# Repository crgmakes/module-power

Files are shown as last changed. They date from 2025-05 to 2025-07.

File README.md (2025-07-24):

# Simple Power Module

All the source files for the simple power module hardware. This module converts 120VAC or 240VAC to 5VDC @ 2A and also provides 3.3V @ 3A.

# Software 

You will need [KiCad](https://kicad.org) to view and edit this design. Click [here](https://www.kicad.org/download/) to download.

# Automation

When the PCB file is checked in, git will automatically build the output gerber files. When a release is made, git will also automatically build both a single PCB production files as well as the panel for production.

---

THE DESIGN IS PROVIDED "AS IS" AND THE AUTHOR DISCLAIMS ALL WARRANTIES WITH REGARD TO THIS DESIGN INCLUDING ALL IMPLIED WARRANTIES OF MERCHANTABILITY AND FITNESS. IN NO EVENT SHALL THE AUTHOR BE LIABLE FOR ANY SPECIAL, DIRECT, INDIRECT, OR CONSEQUENTIAL DAMAGES OR ANY DAMAGES WHATSOEVER RESULTING FROM LOSS OF USE, DATA OR PROFITS, WHETHER IN AN ACTION OF CONTRACT, NEGLIGENCE OR OTHER TORTIOUS ACTION, ARISING OUT OF OR IN CONNECTION WITH THE USE OR PERFORMANCE OF THIS DESIGN.

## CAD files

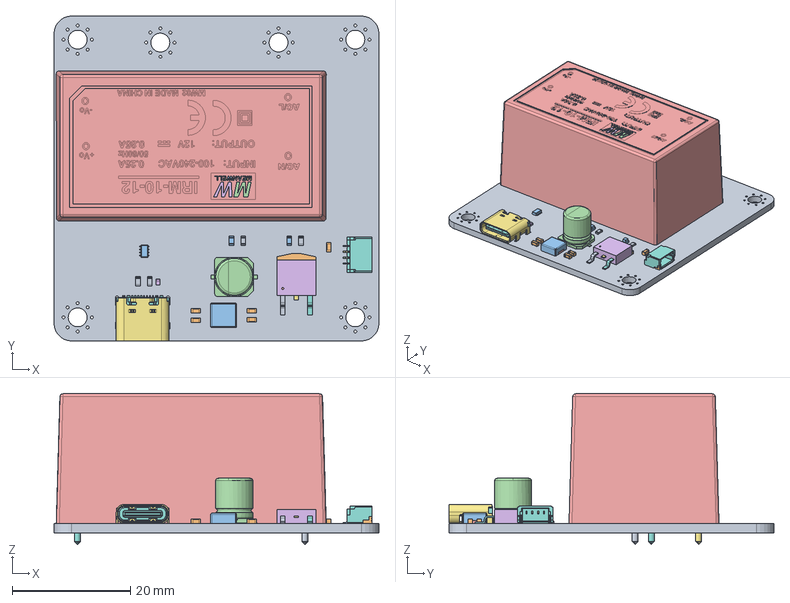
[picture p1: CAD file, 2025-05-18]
cad/power-module.FCStd
55.0 x 55.0 x 25.6 mm
Pcb_a909
SM04B-SRSS-TB v2
SM04B-SRSS-TB v003
SM04B-SRSS-TB v004
SM04B-SRSS-TB v005
SM04B-SRSS-TB v006
SM04B-SRSS-TB v007
SM04B-SRSS-TB v008
R3_R_0603_1608Metric_863d8a166362 x 4
C5_C_0603_1608Metric_8aa0772852b9 x 5
D3_LED_0603_1608Metric_7f0152b93437 x 2
IRM-10-5 v2
IRM-10-5 v003
IRM-10-5 v004
IRM-10-5 v005
IRM-10-5 v006
IRM-10-5 v007
IRM-10-5 v008
IRM-10-5 v009
IRM-10-5 v010
IRM-10-5 v011
IRM-10-5 v012
IRM-10-5 v013
IRM-10-5 v014
IRM-10-5 v015
IRM-10-5 v016
BODY-SOT
C7_CP_Elec_63x77_39e4231ef861
a6dc4f76-8551-11ed-a139-00155d22e2d7_part
a6dc503e-8551-11ed-a139-00155d22e2d7_part
a6dc503e-8551-11ed-a139-00155d22e2d7_part001
D1_D_SOD-882_cb0a772a3ea7
USB4105-GF-A-060_PART2
USB4105-GF-A-060_PART1

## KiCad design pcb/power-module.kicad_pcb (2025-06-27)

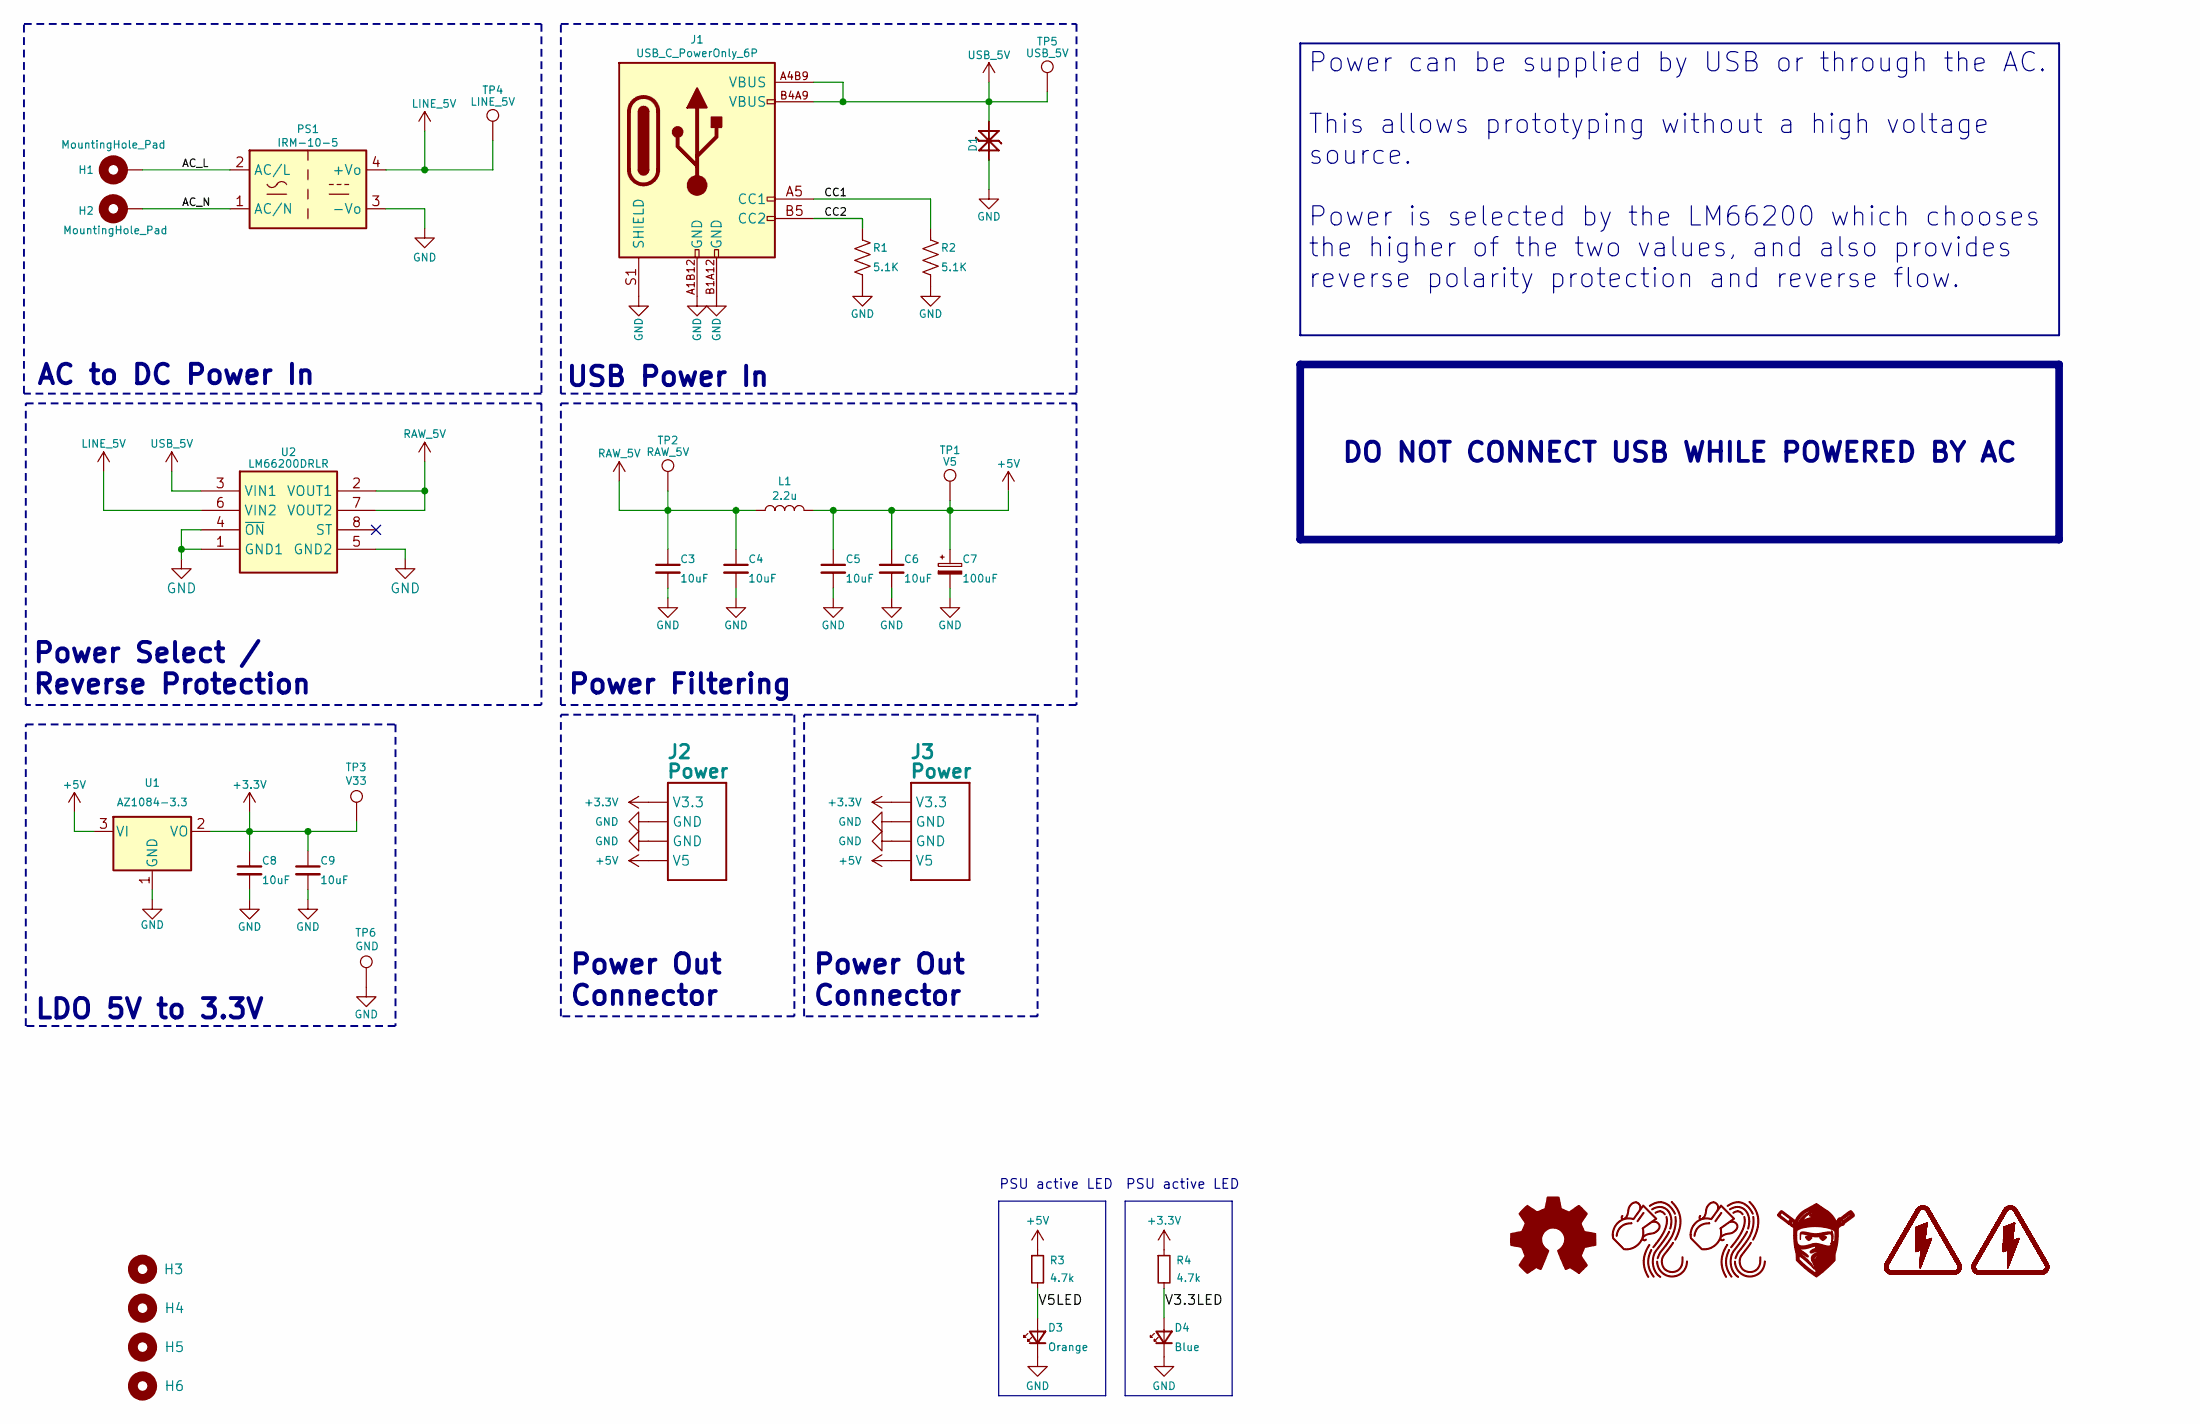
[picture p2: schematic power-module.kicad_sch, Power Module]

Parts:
C3, C4, C5, C6, C8, C9: 10uF; C_0603_1608Metric; MPN CL10A106MO8NQNC; Mouser 187-CL10A106MO8NQNC
C7: 100uF; CP_Elec_6.3x7.7; MPN RVT1V101M0607; Mouser 647-UWT1V101MCL1S
D1: PESD5V5C1BL; DFN1006-2; MPN PESD5V5C1BLYL; Mouser 771-PESD5V5C1BLYL
D3: Orange; LED_0603_1608Metric; MPN XL-1608UOC-06; Mouser 859-LTST-C190KFKT
D4: Blue; LED_0603_1608Metric; MPN XL-1608UBC-04; Mouser 710-150060BS75020
H1, H2: MountingHole_Pad; MountingHole_3.2mm_M3_Pad_Via
H3, H4, H5, H6: MountingHole; MountingHole_3.2mm_M3_Pad_Via
J1: USB_C_PowerOnly_6P; GCT_USB4105-GF-A; MPN USB4105-GF-A-060; Digikey 2073-USB4105-GF-A-060TR-ND
J2, J3: Power; JST_SH_SM04B-SRSS-TB_1x04-1MP_P1.00mm_Horizontal; MPN SM04B-SRSS-TBT(LF)(SN); Mouser 306-SM04BSRSSTBTLFSN
L1: 2.2u; L_Sunlord_MWSA0402S; MPN CMLO0420H2R2MTT; Mouser 673-PA4332222NLT
LOGO1: FNWW Face 10mm
LOGO2: Logo_Open_Hardware_Small; OSHW-Logo_5.7x6mm_SilkScreen
LOGO3: Aquarius Logo 10mm
LOGO4: Aquarius Logo 5mm
PS1: IRM-10-5; Converter_ACDC_MeanWell_IRM-10-xx_THT; MPN IRM-10-5; Mouser 709-IRM10-5
R1, R2: 5.1K; R_0603_1608Metric; MPN FRC0603J512 TS; Mouser 71-CRCW0603J-5.1K-E3
R3, R4: 4.7k; R_0603_1608Metric; MPN FRC0603J472 TS; Mouser 71-CRCW06034K70JNEAC
S1, S2: HIGH-VOLTAGE-5MM
TP1: V5; TestPoint_Pad_D1.0mm
TP2: RAW_5V; TestPoint_Pad_D1.0mm
TP3: V33; TestPoint_Pad_D1.0mm
TP4: LINE_5V; TestPoint_Pad_D1.0mm
TP5: USB_5V; TestPoint_Pad_D1.0mm
TP6: GND; TestPoint_Pad_D1.0mm
U1: AZ1084-3.3; TO-252-2; MPN AZ1084CD-3.3TRG1; Mouser 621-AZ1084CD-3.3TRG1
U2: LM66200DRLR; SOTFL50P160X60-8N; MPN LM66200DRLR; Mouser 595-LM66200DRLR

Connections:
+3.3V: C8.1, C9.1, J2.4 (V3.3), J3.4 (V3.3), R4.1, TP3.1, U1.2 (VO)
+5V: C5.1, C6.1, C7.1, J2.1 (V5), J3.1 (V5), L1.2, R3.1, TP1.1, U1.3 (VI)
/Power Module/AC_L: H1.1, PS1.2 (AC/L)
/Power Module/AC_N: H2.1, PS1.1 (AC/N)
/Power Module/CC1: J1.A5 (CC1), R2.1
/Power Module/CC2: J1.B5 (CC2), R1.1
/Power Module/V3.3LED: D4.2 (A), R4.2
/Power Module/V5LED: D3.2 (A), R3.2
GND: C3.2, C4.2, C5.2, C6.2, C7.2, C8.2, C9.2, D1.1 (K1), D3.1 (K), D4.1 (K), J1.A1B12 (GND), J1.B1A12 (GND), J1.S1 (SHIELD), J2.2 (GND), J2.3 (GND), J3.2 (GND), J3.3 (GND), PS1.3 (-Vo), R1.2, R2.2, TP6.1, U1.1 (GND), U2.1 (GND1), U2.4 (~ON), U2.5 (GND2)
LINE_5V: PS1.4 (+Vo), TP4.1, U2.6 (VIN2)
RAW_5V: C3.1, C4.1, L1.1, TP2.1, U2.2 (VOUT1), U2.7 (VOUT2)
USB_5V: D1.2 (K2), J1.A4B9 (VBUS), J1.B4A9 (VBUS), TP5.1, U2.3 (VIN1)

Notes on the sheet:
AC to DC Power In
Power Out Connector
Power Filtering
USB Power In
PSU active LED
LDO 5V to 3.3V
Power Select / Reverse Protection
DO NOT CONNECT USB WHILE POWERED BY AC
Power can be supplied by USB or through the AC. This allows prototyping without a high voltage source. Power is selected by the LM66200 which chooses the higher of the two values, and also provides reverse polarity protection and reverse flow.

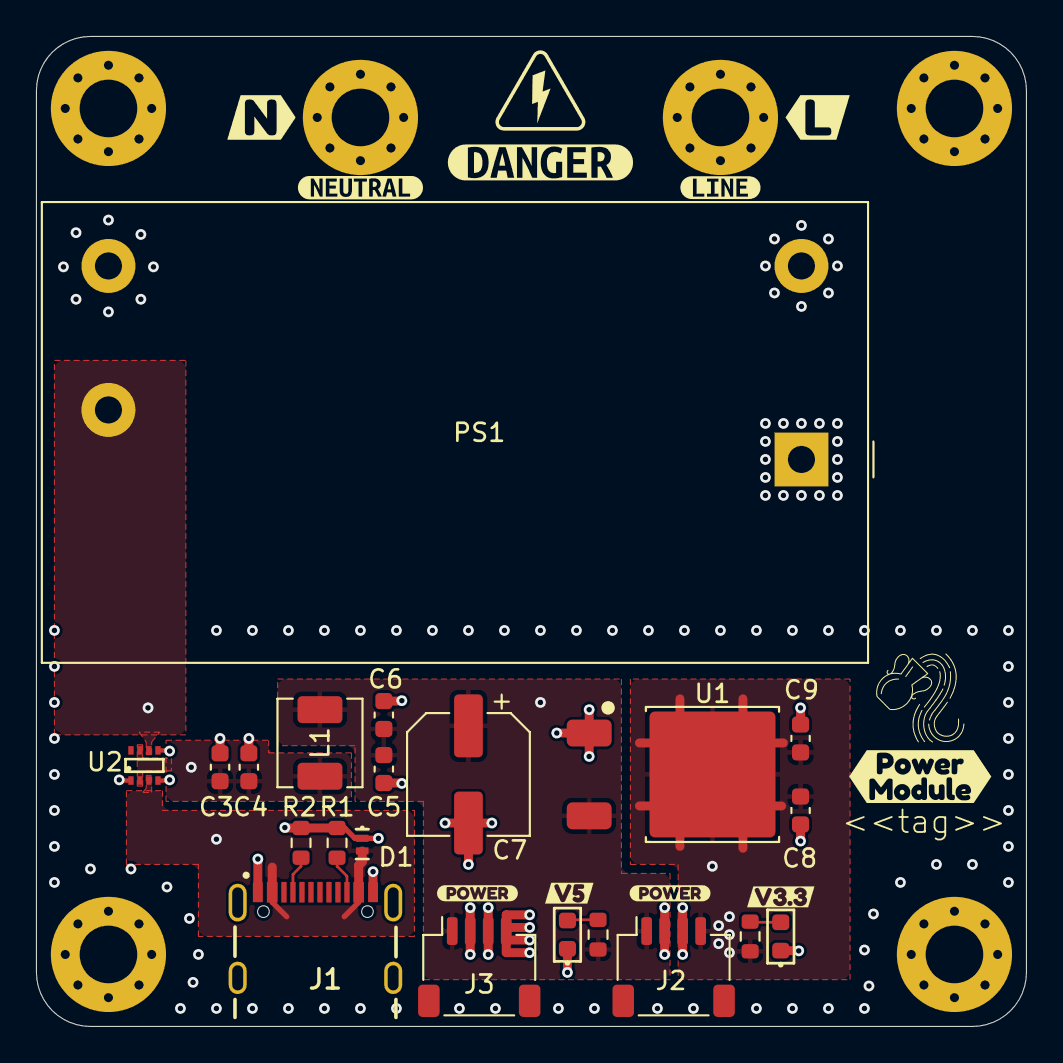
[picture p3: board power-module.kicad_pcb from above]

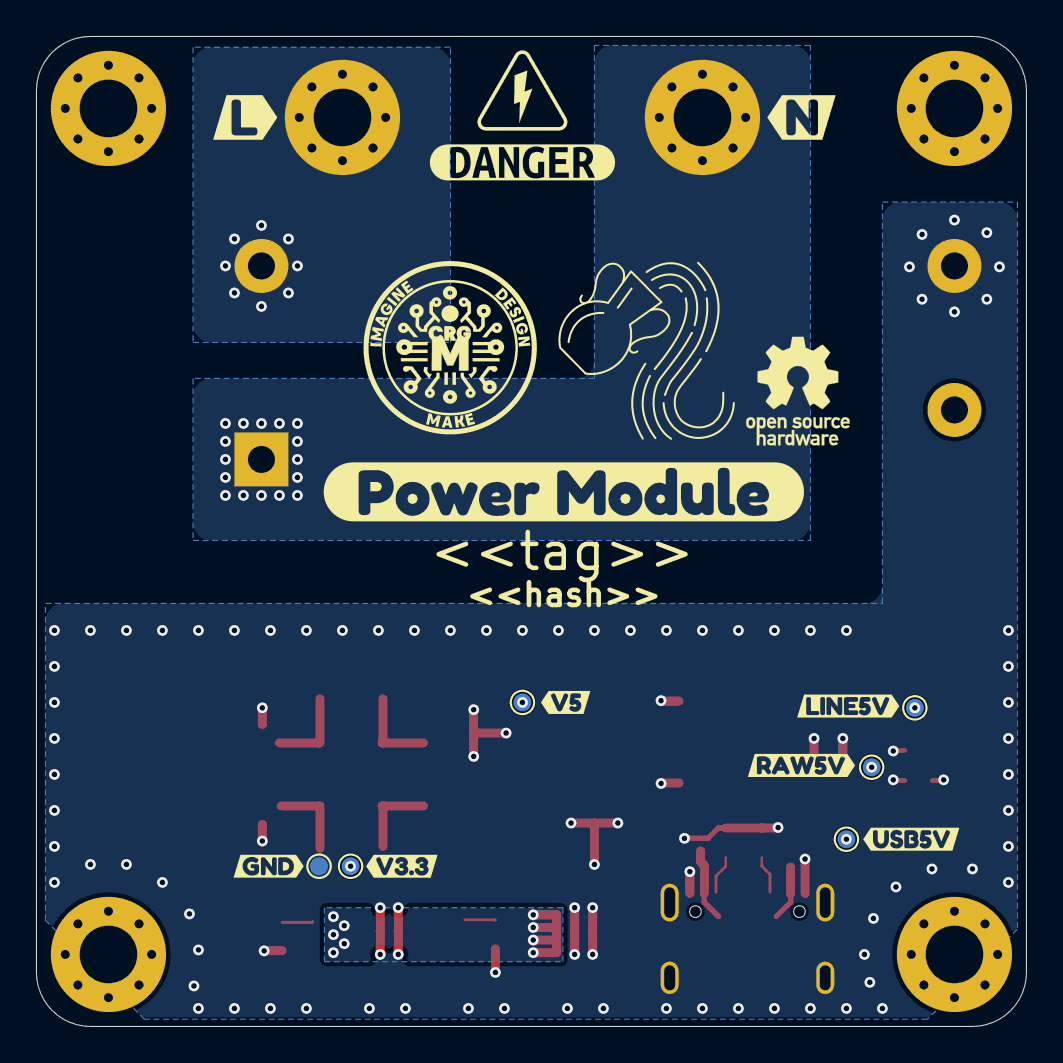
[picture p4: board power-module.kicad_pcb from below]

Board: 4 copper layers, 55.0 x 55.0 mm, 59 parts (20 on the bottom side), 12 nets.

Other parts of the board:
kibuzzard-67E1D06C, kibuzzard-67E1D06C#2: G***; kibuzzard-67E1D06C
kibuzzard-67F465A8: G***; kibuzzard-67F465A8
kibuzzard-67F873C9: G***; kibuzzard-67F873C9
kibuzzard-681CF78D: G***; kibuzzard-681CF78D
kibuzzard-6823F461: G***; kibuzzard-6823F461
kibuzzard-6823F476: G***; kibuzzard-6823F476
kibuzzard-685744FC: G***; kibuzzard-685744FC
kibuzzard-685745D7: G***; kibuzzard-685745D7
kibuzzard-685745EF: G***; kibuzzard-685745EF
kibuzzard-6857402F: G***; kibuzzard-6857402F
kibuzzard-6857403E: G***; kibuzzard-6857403E
kibuzzard-6857452D: G***; kibuzzard-6857452D
kibuzzard-6857464E: G***; kibuzzard-6857464E
kibuzzard-6857482E: G***; kibuzzard-6857482E
kibuzzard-68084394: G***; kibuzzard-68084394
kibuzzard-68574501: G***; kibuzzard-68574501
kibuzzard-68574508: G***; kibuzzard-68574508
kibuzzard-68574514: G***; kibuzzard-68574514
kibuzzard-68574631: G***; kibuzzard-68574631

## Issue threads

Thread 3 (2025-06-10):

LED too bright

cyberreefguru, 2025-06-10:
Increase resistance to lower brightness.
Current value is 1K - consider 4.7K to reduce total part count, even if that's too high.

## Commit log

2025-04-09 Initial checkin
    [power-module-simple.kicad_pcb, power-module-simple.kicad_sch]
2025-04-10 Attribute updates; generated production files
    [bom.csv, designators.csv, positions.csv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]
2025-04-11 Updated silkscreen and LED size
    [power-module-simple.kicad_pcb, power-module-simple.kicad_sch]
2025-04-29 Changed switching mechanism; updated power delivery for v3.3
    [power-module-simple.kicad_pcb, power-module-simple.kicad_sch]
2025-05-08 Fixed AZ1084 footprint
    Fixed USB-C Connector / symbol mismatch
    Moved parts around
    Moved USB-C connector from overhanging.
    Generated ibom.
    [bom.csv, designators.csv, positions.csv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]
2025-05-08 Renamed to power-module; updated silkscreen and some symbols
    [power-module-simple.kicad_pcb, power-module-simple.kicad_sch, power-module.kicad_pcb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]
2025-05-10 generated fabrication files
    [bom.csv, designators.csv, positions.csv]
2025-05-14 Changed LED colors; regenerated panels
    [power-module.kicad_pcb, power-module.kicad_sch]
2025-05-15 Changed to vscore instead of mouse bites
    re-panelized.
    [bom.csv, designators.csv, positions.csv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]
2025-05-16 Updated connector symbol and back annotation
    [power-module.kicad_pcb, power-module.kicad_sch]
2025-05-16 revamped using different examples
    [power-module.kicad_pcb, power-module.kicad_sch]
2025-05-16 getting tired doing it this way....
2025-05-16 optimized script; still fighting some errors
    [power-module.kicad_pcb]
2025-05-17 Updated parameters on some parts
    [power-module.kicad_pcb, power-module.kicad_sch]
2025-05-17 Added extras and crgm lib.
    [power-module.kicad_pcb]
2025-05-17 continue to resolve library issues (pcbdraw)
2025-05-17 fixed syntax error with pcbdraw lib
2025-05-18 Updated models and alignment
    [power-module.FCStd, power-module.kicad_pcb]
2025-05-18 fixed model expansion of usb connector; changed script to use sed
    [power-module.kicad_pcb]
2025-05-24 Added panelization; cleaned up
    [bom.csv, designators.csv, positions.csv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]
2025-05-24 switched to zip action
2025-05-24 switched to fab kit to capture rotations
2025-05-25 moved ibom to directory; zipped gerbers
2025-05-25 fixed back option for zip of gerbers
2025-05-25 adjusted gerber directories
2025-05-25 switched to fabkit for single pcb
2025-05-25 only copy pcb and sch to pcb directory
2025-05-26 fixed model locations in pcb; reworking to use import
    [power-module.kicad_pcb]
2025-05-26 fixed model name and locations
    [power-module.kicad_pcb]
2025-05-26 Fixed soldermask on USB connector; cleaned up scripts
    [power-module.kicad_pcb]
2025-05-26 Fixed USB model path and position, and TO-252 position
    [power-module.kicad_pcb]
2025-05-27 alternate inductor - primary is out of stock
    [power-module.kicad_pcb, power-module.kicad_sch]
2025-05-28 Part swap; moved from 2x2 panel to 1x2 panel
    [power-module.kicad_pcb, power-module.kicad_sch]
2025-05-29 Added tag to pcb to capture version on release; updated check in script to fill in tag
    [power-module.kicad_pcb]
2025-05-31 Separated 22uF into two 10uF; rerouted everything for better layout
    [power-module.kicad_pcb, power-module.kicad_sch]
2025-05-31 Fixed file name in script; fixed H3 name missing in schematic
    [power-module.kicad_pcb, power-module.kicad_sch]
2025-06-01 Added dimensions to PCB
    [power-module.kicad_pcb]
2025-06-21 Updated resistor values
    [power-module.kicad_pcb, power-module.kicad_sch]
2025-06-21 Minor clean up and dimensioning
    [power-module.kicad_pcb, power-module.kicad_sch]
2025-06-21 Updated mounting hole footprint and dimensions
    [power-module.kicad_pcb]
2025-06-21 Updated layers
    [power-module.kicad_pcb]
2025-06-22 Added second power connector and TP for GND
    [power-module.kicad_pcb, power-module.kicad_sch]
2025-06-22 Changed to multi-sheet
    [power-module.kicad_pcb, power-processing.kicad_sch, requirements.kicad_sch]
2025-06-26 Updated frame template
    [power-module.kicad_pcb, power-processing.kicad_sch, requirements.kicad_sch]
2025-06-27 Updated worksheet template
    [power-module.kicad_pcb, power-processing.kicad_sch, requirements.kicad_sch]
2025-06-27 Updated worksheet template and logo
    [power-module.kicad_pcb]
2025-07-13 Update license and PCB schematic details
    Clarified KiCAD library licensing in LICENSE.md to reference the kicad-library repo. Added a PCB specification text box to requirements.kicad_sch. Updated image data in power-module.kicad_sch for imp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
    [requirements.kicad_sch]
2025-12-16 Added second power connector
    Rearranged.
    Added additional filtering
    [power.kicad_sch, requirements.kicad_sch]
2025-12-27 Updated 100uF to 220uF
    Adjusted part numbers
    [power.kicad_sch]
2025-12-29 Changed power connnectors
    Changed to 3 pin power connector for +5v only.
    Power input limited to AC or USB only
    Added 220uF cap to 3.3v out at LDO
    Added TVS to power connectors
    [power.kicad_sch]
2025-12-29 Fixed connector spacing
